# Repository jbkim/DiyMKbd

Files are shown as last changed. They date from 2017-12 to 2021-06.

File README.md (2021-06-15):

# Diy Mechanical Keyboard

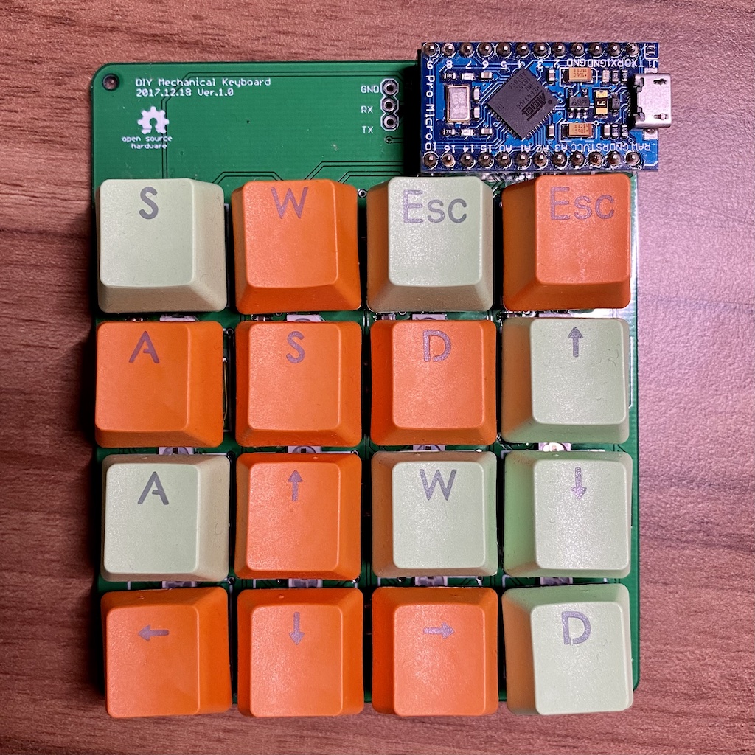
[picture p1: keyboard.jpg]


### Hardware
- WS2812B NeoPixel: 없어도 동작함 [Link](https://www.adafruit.com/product/1655)
- 기계식 키스위치: http://www.coupang.com/vp/products/24294727

### Firmware
- MyDiyKbd: 실제 동작하는 코드
- Tets_Neopixel, Tets_Neopixel2, Test_key : 테스트용 코드

### Order
- 중국 PCB 업체 https://jlcpcb.com/

### 참고
- http://blog.komar.be/how-to-make-a-keyboard-the-matrix/
- 아두이노 Keyboard Modifiers https://www.arduino.cc/en/Reference/KeyboardModifiers
- Mac 키보드 단축키 https://support.apple.com/ko-kr/HT201236

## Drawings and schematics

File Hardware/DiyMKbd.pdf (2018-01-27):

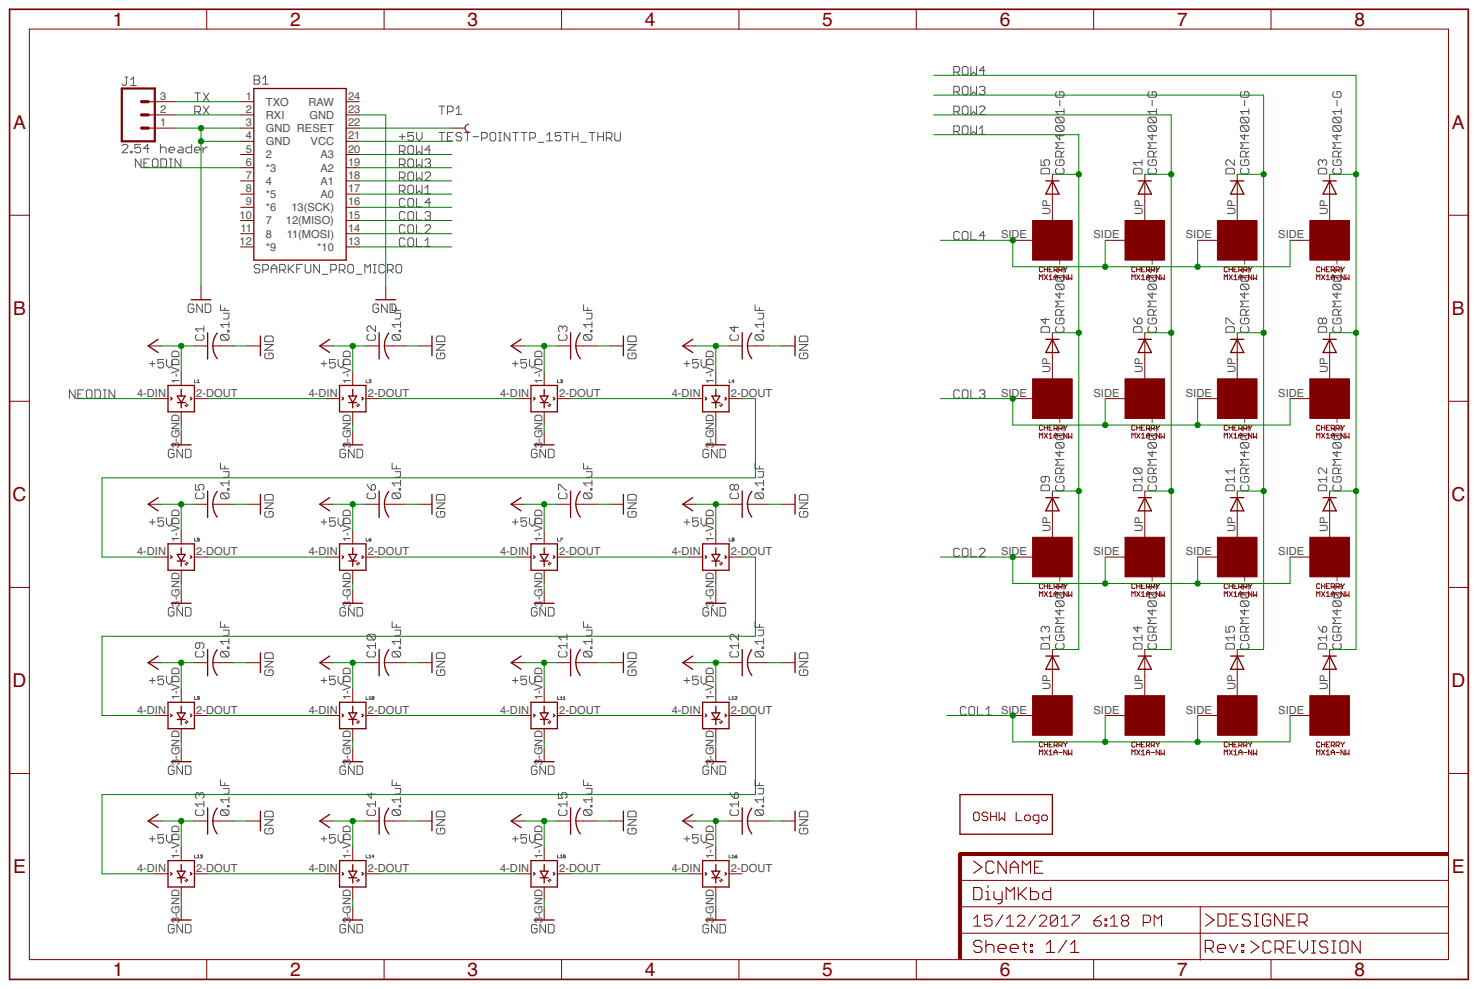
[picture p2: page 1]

UP UP A SIDE UP UP A SIDE UP UP A SIDE UP UP A SIDE UP UP A SIDE UP UP A SIDE UP UP A SIDE UP UP A SIDE UP UP A SIDE UP UP A SIDE UP UP A SIDE UP UP A SIDE UP UP A SIDE UP UP A SIDE UP UP A SIDE UP UP A SIDE 2 5 *3 6 4 7 *5 8 *6 9 7 10 8 11 *9 12 *10 13 11(MOSI) 14 12(MISO) 15 13(SCK) 16 A0 17 A1 18 A2 19 A3 20 GND 4 GND 23 RAW 24 GND 3 RESET 22 RXI 2 TXO 1 VCC 21 123 4-DIN 2-DOUT 1-VDD 3-GND 4-DIN 2-DOUT 1-VDD 3-GND 4-DIN 2-DOUT 1-VDD 3-GND 4-DIN 2-DOUT 1-VDD 3-GND 4-DIN 2-DOUT 1-VDD 3-GND 4-DIN 2-DOUT 1-VDD 3-GND 4-DIN 2-DOUT 1-VDD 3-GND 4-DIN 2-DOUT 1-VDD 3-GND 4-DIN 2-DOUT 1-VDD 3-GND 4-DIN 2-DOUT 1-VDD 3-GND 4-DIN 2-DOUT 1-VDD 3-GND 4-DIN 2-DOUT 1-VDD 3-GND 4-DIN 2-DOUT 1-VDD 3-GND 4-DIN 2-DOUT 1-VDD 3-GND 4-DIN 2-DOUT 1-VDD 3-GND 4-DIN 2-DOUT 1-VDD 3-GND ABCDE 1 2 3 4 5 6 7 8 ABCDE 1 2 3 4 5 6 7 8

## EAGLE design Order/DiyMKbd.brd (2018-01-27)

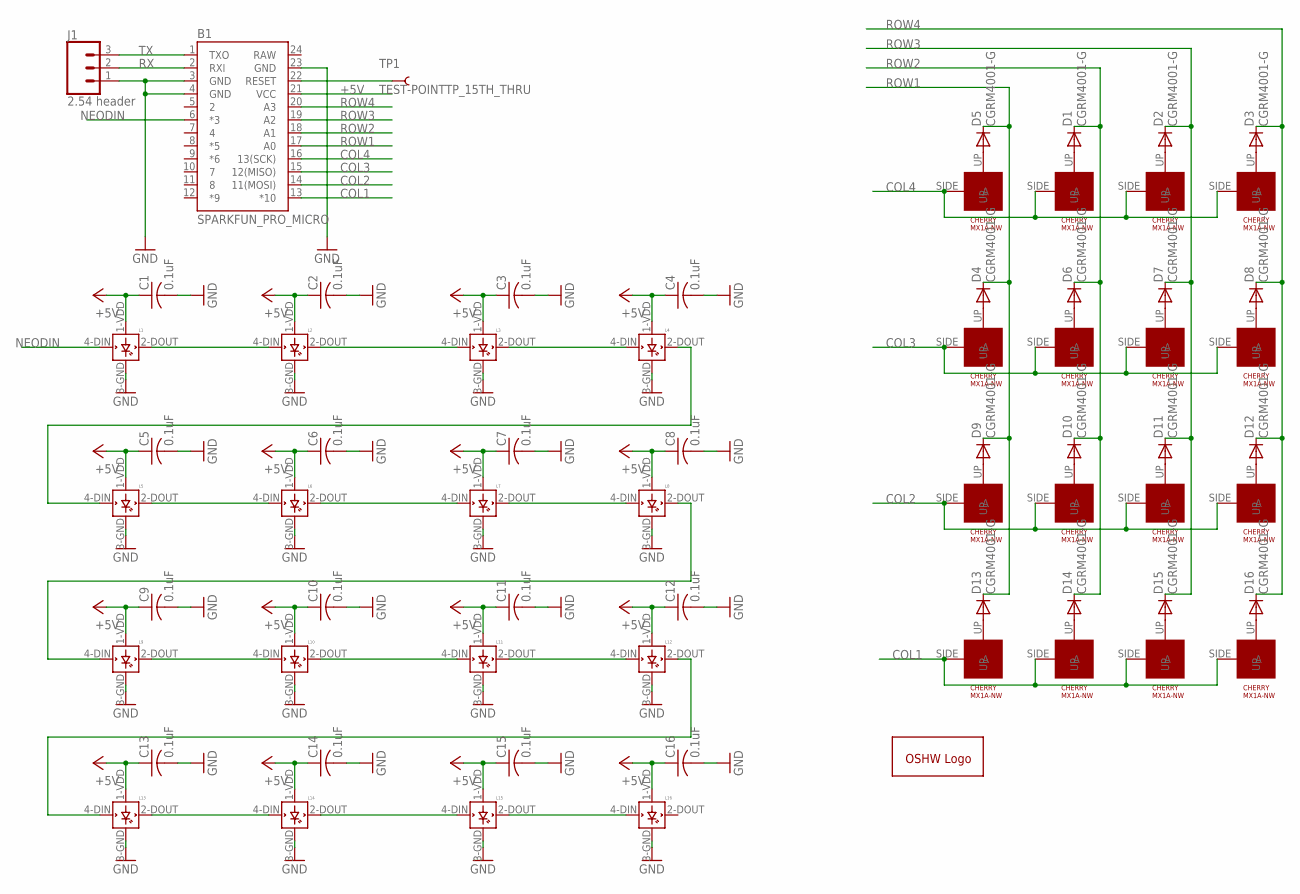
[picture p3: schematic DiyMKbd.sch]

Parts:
B1: SPARKFUN_PRO_MICRO
C1, C2, C3, C4, C5, C6, C7, C8, C9, C10, C11, C12, C13, C14, C15, C16: 0.1uF; C0603
D1, D2, D3, D4, D5, D6, D7, D8, D9, D10, D11, D12, D13, D14, D15, D16: CGRM4001-G; SOD-123_MINI-SMA
GOLD_ORB_SM1: OSHWLOGOLOGO5MM; OSHW_5MM
J1: 2.54 header; 1X03_LOCK
L1, L2, L3, L4, L5, L6, L7, L8, L9, L10, L11, L12, L13, L14, L15, L16: WS2812B
TP1: TEST-POINTTP_15TH_THRU; TP_15TH
U$1, U$2, U$3, U$4, U$7, U$8, U$9, U$10, U$19, U$20, U$21, U$22, U$25, U$26, U$27, U$28: CHERRY-MX1A-E1NW; CHERRYMX-NN

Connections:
+5V: B1.21 (VCC), C1.1, C2.1, C3.1, C4.1, C5.1, C6.1, C7.1, C8.1, C9.1, C10.1, C11.1, C12.1, C13.1, C14.1, C15.1, C16.1, L1.1-VDD (VDD), L2.1-VDD (VDD), L3.1-VDD (VDD), L4.1-VDD (VDD), L5.1-VDD (VDD), L6.1-VDD (VDD), L7.1-VDD (VDD), L8.1-VDD (VDD), L9.1-VDD (VDD), L10.1-VDD (VDD), L11.1-VDD (VDD), L12.1-VDD (VDD), L13.1-VDD (VDD), L14.1-VDD (VDD), L15.1-VDD (VDD), L16.1-VDD (VDD)
COL1: B1.13 (*10), U$25.SIDE (A), U$26.SIDE (A), U$27.SIDE (A), U$28.SIDE (A)
COL2: B1.14 (11(MOSI)), U$7.SIDE (A), U$8.SIDE (A), U$9.SIDE (A), U$10.SIDE (A)
COL3: B1.15 (12(MISO)), U$1.SIDE (A), U$2.SIDE (A), U$3.SIDE (A), U$4.SIDE (A)
COL4: B1.16 (13(SCK)), U$19.SIDE (A), U$20.SIDE (A), U$21.SIDE (A), U$22.SIDE (A)
GND: B1.3 (GND), B1.4 (GND), B1.23 (GND), C1.2, C2.2, C3.2, C4.2, C5.2, C6.2, C7.2, C8.2, C9.2, C10.2, C11.2, C12.2, C13.2, C14.2, C15.2, C16.2, J1.1, L1.3-GND (GND), L2.3-GND (GND), L3.3-GND (GND), L4.3-GND (GND), L5.3-GND (GND), L6.3-GND (GND), L7.3-GND (GND), L8.3-GND (GND), L9.3-GND (GND), L10.3-GND (GND), L11.3-GND (GND), L12.3-GND (GND), L13.3-GND (GND), L14.3-GND (GND), L15.3-GND (GND), L16.3-GND (GND)
unnamed: D5.A, U$19.UP
unnamed: D1.A, U$20.UP
unnamed: D2.A, U$21.UP
unnamed: D3.A, U$22.UP
unnamed: L1.2-DOUT (DOUT), L2.4-DIN (DIN)
unnamed: L2.2-DOUT (DOUT), L3.4-DIN (DIN)
unnamed: D4.A, U$2.UP
unnamed: D6.A, U$1.UP
unnamed: D7.A, U$3.UP
unnamed: D8.A, U$4.UP
unnamed: L3.2-DOUT (DOUT), L4.4-DIN (DIN)
unnamed: L4.2-DOUT (DOUT), L5.4-DIN (DIN)
unnamed: L5.2-DOUT (DOUT), L6.4-DIN (DIN)
unnamed: L6.2-DOUT (DOUT), L7.4-DIN (DIN)
unnamed: L7.2-DOUT (DOUT), L8.4-DIN (DIN)
unnamed: L8.2-DOUT (DOUT), L9.4-DIN (DIN)
unnamed: L9.2-DOUT (DOUT), L10.4-DIN (DIN)
unnamed: L10.2-DOUT (DOUT), L11.4-DIN (DIN)
unnamed: D9.A, U$7.UP
unnamed: D10.A, U$8.UP
unnamed: D11.A, U$9.UP
unnamed: D12.A, U$10.UP
unnamed: L11.2-DOUT (DOUT), L12.4-DIN (DIN)
unnamed: L12.2-DOUT (DOUT), L13.4-DIN (DIN)
unnamed: D13.A, U$25.UP
unnamed: D14.A, U$26.UP
unnamed: D15.A, U$27.UP
unnamed: D16.A, U$28.UP
unnamed: L13.2-DOUT (DOUT), L14.4-DIN (DIN)
unnamed: L14.2-DOUT (DOUT), L15.4-DIN (DIN)
unnamed: L15.2-DOUT (DOUT), L16.4-DIN (DIN)
NEODIN: B1.6 (*3), L1.4-DIN (DIN)
RAW: B1.24 (RAW)
RESET: B1.22 (RESET), TP1.P$1
ROW1: B1.17 (A0), D4.C, D5.C, D9.C, D13.C
ROW2: B1.18 (A1), D1.C, D6.C, D10.C, D14.C
ROW3: B1.19 (A2), D2.C, D7.C, D11.C, D15.C
ROW4: B1.20 (A3), D3.C, D8.C, D12.C, D16.C
RX: B1.2 (RXI), J1.2
TX: B1.1 (TXO), J1.3

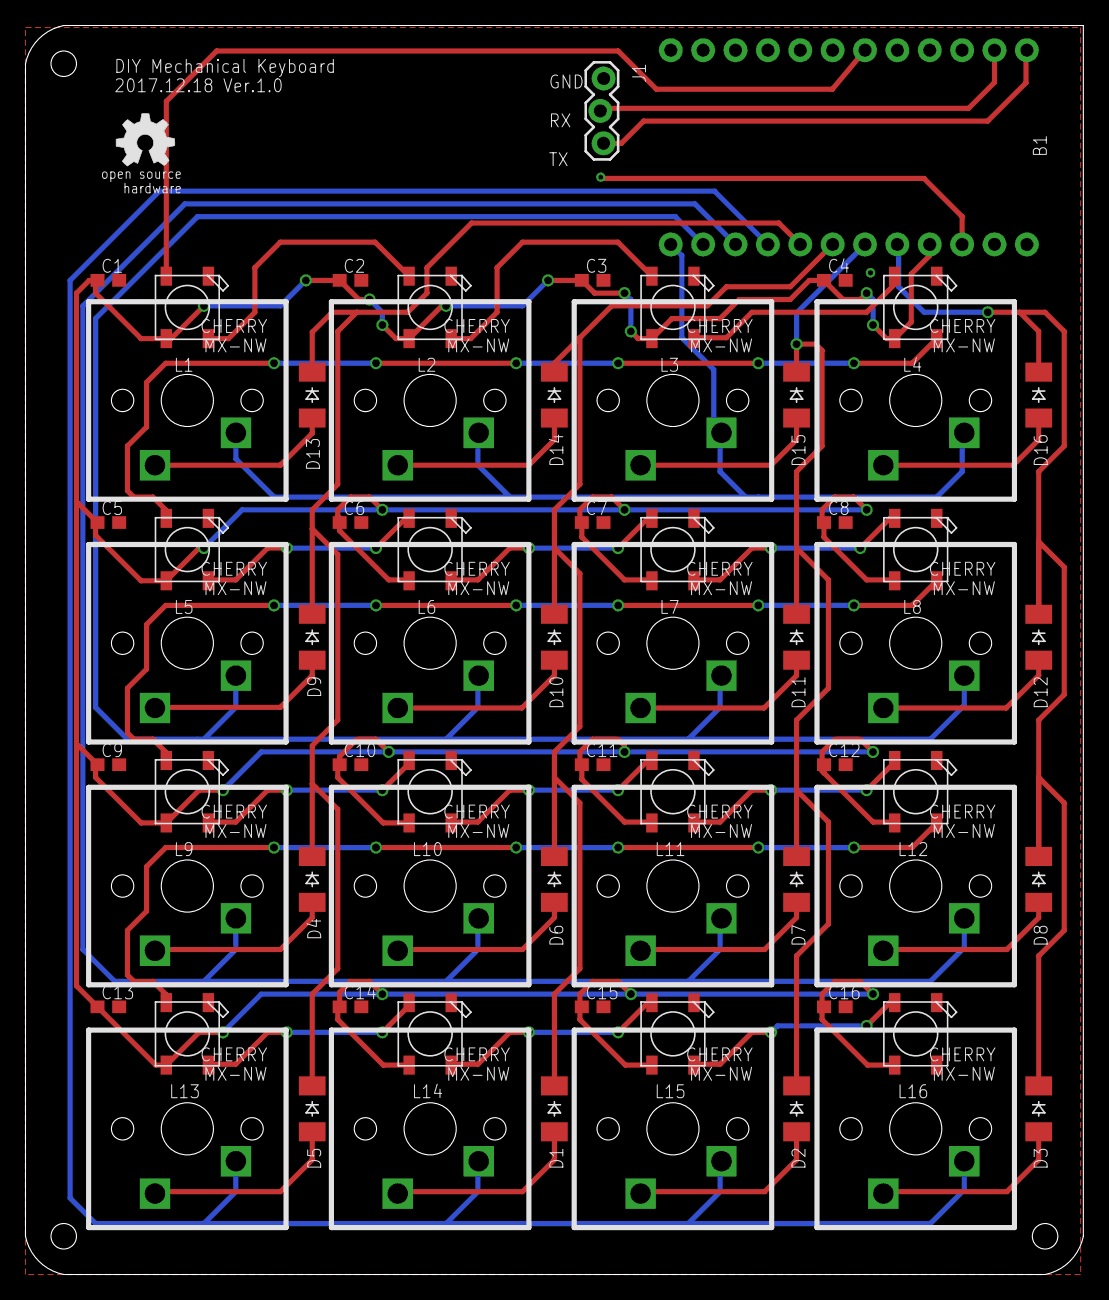
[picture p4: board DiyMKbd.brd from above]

Board: 2 copper layers, 83.0 x 98.0 mm, 68 parts (0 on the bottom side), 45 nets.

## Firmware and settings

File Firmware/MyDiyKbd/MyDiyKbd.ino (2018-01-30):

#include <HID-Project.h>
#include <Adafruit_NeoPixel.h>

#define NUM_BTN_COLS (4) // Number of switch columns (isolating diode anode)
#define NUM_BTN_ROWS (4) // Number of switch rows (isolating diode cathode)

// Debounce built-in to the code. This sets the number of button
// high or low senses that trigger a press or release
#define MAX_DEBOUNCE (3)
#define KEY_COMMAND KEY_LEFT_GUI

// Which pin on the Arduino is connected to the NeoPixels?
#define PIN            3

// How many NeoPixels are attached to the Arduino?
#define NUMPIXELS      16

static const uint8_t btnRowPins[NUM_BTN_ROWS] = {A0,A1,A2,A3}; // Pins connected to switch rows (2)
static const uint8_t btnColPins[NUM_BTN_COLS] = {10,16,14,15};; // Pins connected to switch columns (1)
static int8_t debounce_count[NUM_BTN_COLS][NUM_BTN_ROWS]; // One debounce counter per switch

Adafruit_NeoPixel pixels = Adafruit_NeoPixel(NUMPIXELS, PIN, NEO_GRB + NEO_KHZ800);

void showPixels(uint8_t row, uint8_t col, int r, int g, int b)
{
   pixels.setPixelColor(col*4 + row, pixels.Color(r,g,b));
   pixels.show();
   // delay(100);
}

void setup()
{
  uint8_t i, j;

  setupSwitchPins();

  // Initialize the debounce counter array
  for (i = 0; i < NUM_BTN_COLS; i++)
  {
    for (j = 0; j < NUM_BTN_ROWS; j++)
    {
      debounce_count[i][j] = 0;
    }
  }

// Initialize USB keyboard
  Keyboard.begin();
  
// Initialize Neopixel
  pixels.begin();
  colorWipe(pixels.Color(127, 127, 127), 50); // White

// Off
  for(i = 0; i < 4 ; i++){
    for(j = 0; j < 4 ; j++){
      showPixels(i,j,0,0,0);
      delay(50);
    }
  }
}

void loop() 
{
  scan();
}

static void scan()
{
  static uint8_t currentRow = 0;
  uint8_t i, j; // for loop counters
  int key;

  // Select current row, and write all components on that row LOW.
  // That'll set the LED anode's LOW, and write the switch "2" pins LOW.
  // If diodes were added, "2' should be connected to the diode cathode
  digitalWrite(btnRowPins[currentRow], LOW);
  // digitalWrite(ledRowPins[currentRow], LOW);

  // Scan through switches on this row:
  for ( j = 0; j < NUM_BTN_COLS; j++)
  {
    // Read the button. If it's pressed, it should be LOW.
    if (digitalRead(btnColPins[j]) == LOW)
    {
      if ( debounce_count[currentRow][j] < MAX_DEBOUNCE)
      { // Increment a debounce counter
        debounce_count[currentRow][j]++;
        if ( debounce_count[currentRow][j] == MAX_DEBOUNCE )
        { // If debounce counter hits MAX_DEBOUNCE (default: 3)
          // Trigger key press -- Do anything here...
          // Serial.print("Key pressed "); 
          // Serial.println((currentRow * NUM_BTN_COLS) + j);

          showPixels(currentRow, j, 0, 255, 0);  // green
          key = (currentRow * NUM_BTN_COLS) + j;
          // key = key + '0';
          // Keyboard.press(key); // Will display 0123456789:;<=>>?
          run_cmd(key);
        }
      }
    }
    else // Otherwise, button is released
    {
      if ( debounce_count[currentRow][j] > 0)
      { 
        debounce_count[currentRow][j]--; // Decrement debounce counter
        if ( debounce_count[currentRow][j] == 0 )
        { // If debounce counter hits 0
          // Trigger key release -- Do anything here...
          showPixels(currentRow, j, 0,0,0);  
          Keyboard.releaseAll();
        }
      }
    }
  }

  // Once done scanning, de-select the switch and LED rows
  // by writing them HIGH.
  digitalWrite(btnRowPins[currentRow], HIGH);

  // Increment currentRow, so next time we scan the next row
  currentRow++;
  // if (currentRow >= NUM_LED_ROWS)
  if (currentRow >= NUM_BTN_ROWS)
  {
    currentRow = 0;
  }
}

static void setupSwitchPins()
{
  uint8_t i;

  // Button drive rows - written LOW when active, HIGH otherwise
  for (i = 0; i < NUM_BTN_ROWS; i++)
  {
    pinMode(btnRowPins[i], OUTPUT);

    // with nothing selected by default
    digitalWrite(btnRowPins[i], HIGH);
  }

  // Buttn select columns. Pulled high through resistor. Will be LOW when active
  for (i = 0; i < NUM_BTN_COLS; i++)
  {
    pinMode(btnColPins[i], INPUT_PULLUP);
  }
}


// Fill the dots one after the other with a color
void colorWipe(uint32_t c, uint8_t wait) {
  for(uint16_t i = 0; i < pixels.numPixels(); i++) {
    pixels.setPixelColor(i, c);
    pixels.show();
    delay(wait);
  }
}

// Input a value 0 to 255 to get a color value.
// The colours are a transition r - g - b - back to r.
uint32_t Wheel(byte WheelPos) 
{
  WheelPos = 255 - WheelPos;
  if(WheelPos < 85) {
    return pixels.Color(255 - WheelPos * 3, 0, WheelPos * 3);
  }
  if(WheelPos < 170) {
    WheelPos -= 85;
    return pixels.Color(0, WheelPos * 3, 255 - WheelPos * 3);
  }
  WheelPos -= 170;
  return pixels.Color(WheelPos * 3, 255 - WheelPos * 3, 0);
}


void rainbow(uint8_t wait) {
  uint16_t i, j;

  for(j = 0; j < 256; j++) {
    for(i = 0; i < pixels.numPixels(); i++) {
      pixels.setPixelColor(i, Wheel((i+j) & 255));
    }
    pixels.show();
    delay(wait);
  }
}


void run_cmd(uint8_t key)
{
  switch(key) {
    // 1
    case 0:
      Keyboard.press(KEY_LEFT_GUI);
      Keyboard.press(KEY_LEFT_CTRL);
      Keyboard.press('q');    
      break;    
    case 1:
      // select all
      Keyboard.press(KEY_LEFT_GUI);
      Keyboard.press('a');    
      break;
    case 2:
      // alt + space = Spotlight
      Keyboard.press(KEY_LEFT_ALT);
      Keyboard.press(' ');  
      break;
    case 3:
      Keyboard.press(KEY_LEFT_ARROW);
      break;
    // 2
    case 4:
      // close window
      Keyboard.press(KEY_LEFT_GUI);
      Keyboard.press('w');    
      break;
    case 5:
      break;
    case 6:
      Keyboard.press(KEY_UP_ARROW);
      break;
    case 7:
      Keyboard.press(KEY_DOWN_ARROW);
      break;
    // 3
    case 8:
      break;
    case 9:
      break;
    case 10:
      break;
    case 11:
      Keyboard.press(KEY_RIGHT_ARROW);    
      break;

    // 4
    case 12:
      // log out
      Keyboard.press(KEY_LEFT_GUI);
      // Shift-Q logs out:
      Keyboard.press(KEY_LEFT_SHIFT);
      Keyboard.press('q');      
      delay(100);
      Keyboard.releaseAll();
      // enter:
      // Keyboard.write(KEY_RETURN);      
      break;
    case 13:
      Keyboard.press(KEY_PAGE_UP);
      break;
    case 14:
      Keyboard.press(KEY_PAGE_DOWN);
      break;
    case 15:
      // enter
      Keyboard.write(KEY_RETURN);   
      break;
  }
}

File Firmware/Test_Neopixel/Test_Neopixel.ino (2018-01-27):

#include <NeoPixelAnimator.h>
#include <NeoPixelBrightnessBus.h>
#include <NeoPixelBus.h>

// NeoPixel Ring simple sketch (c) 2013 Shae Erisson
// released under the GPLv3 license to match the rest of the AdaFruit NeoPixel library

#include <Adafruit_NeoPixel.h>
#ifdef __AVR__
  #include <avr/power.h>
#endif

// Which pin on the Arduino is connected to the NeoPixels?
// On a Trinket or Gemma we suggest changing this to 1
#define PIN            3
#define GAP           20
// How many NeoPixels are attached to the Arduino?
#define NUMPIXELS      16

// When we setup the NeoPixel library, we tell it how many pixels, and which pin to use to send signals.
// Note that for older NeoPixel strips you might need to change the third parameter--see the strandtest
// example for more information on possible values.
Adafruit_NeoPixel pixels = Adafruit_NeoPixel(NUMPIXELS, PIN, NEO_GRB + NEO_KHZ800);
#define HSB
int delayval = 10; // delay for half a second
uint8_t c[3];

void hsb2rgb(uint16_t index, uint8_t sat, uint8_t bright, uint8_t color[3])
{
  uint16_t r_temp, g_temp, b_temp;
  uint8_t index_mod;
  uint8_t inverse_sat = (sat ^ 255);

  index = index % 768;
  index_mod = index % 256;

  if (index < 256)
  {
    r_temp = index_mod ^ 255;
    g_temp = index_mod;
    b_temp = 0;
  }

  else if (index < 512)
  {
    r_temp = 0;
    g_temp = index_mod ^ 255;
    b_temp = index_mod;
  }

  else if ( index < 768)
  {
    r_temp = index_mod;
    g_temp = 0;
    b_temp = index_mod ^ 255;
  }

  else
  {
    r_temp = 0;
    g_temp = 0;
    b_temp = 0;
  }

  r_temp = ((r_temp * sat) / 255) + inverse_sat;
  g_temp = ((g_temp * sat) / 255) + inverse_sat;
  b_temp = ((b_temp * sat) / 255) + inverse_sat;

  r_temp = (r_temp * bright) / 255;
  g_temp = (g_temp * bright) / 255;
  b_temp = (b_temp * bright) / 255;

  color[0]  = (uint8_t)r_temp;
  color[1]  = (uint8_t)g_temp;
  color[2] = (uint8_t)b_temp;
}



void setup() {
  // This is for Trinket 5V 16MHz, you can remove these three lines if you are not using a Trinket
#if defined (__AVR_ATtiny85__)
  if (F_CPU == 16000000) clock_prescale_set(clock_div_1);
#endif
  // End of trinket special code
  Serial.begin(115200);
  pixels.begin(); // This initializes the NeoPixel library.
  pinMode(10,INPUT);
}

void loop() {
#if 0
  // For a set of NeoPixels the first NeoPixel is 0, second is 1, all the way up to the count of pixels minus one.
  int dr = digitalRead(10);
  Serial.print("Read Data:");
  Serial.println(dr);
  if(dr){
   pixels.setPixelColor(0,pixels.Color(0,255,0));
   pixels.show();
   delay(100);
    
  }else{
   pixels.setPixelColor(0,pixels.Color(255,0,0));
   pixels.show();
   delay(100);
    
  }
#endif

    for(int j = 0; j < 767 ; j+=5){
       
       for(int i=0;i<NUMPIXELS;i++){
        hsb2rgb(j+GAP*0,255,255,c);
         pixels.setPixelColor(0,pixels.Color(c[0],c[1],c[2])); // Moderately bright green color.
         hsb2rgb((j+GAP*1)%767,255,255,c);
        pixels.setPixelColor(1,pixels.Color(c[0],c[1],c[2])); // Moderately bright green color.
        pixels.setPixelColor(4,pixels.Color(c[0],c[1],c[2])); // Moderately bright green color.
         hsb2rgb((j+GAP*2)%767,255,255,c);
         pixels.setPixelColor(2,pixels.Color(c[0],c[1],c[2])); // Moderately bright green color.
        pixels.setPixelColor(5,pixels.Color(c[0],c[1],c[2])); // Moderately bright green color.
        pixels.setPixelColor(8,pixels.Color(c[0],c[1],c[2])); // Moderately bright green color.
        hsb2rgb((j+GAP*3)%767,255,255,c);
         pixels.setPixelColor(3,pixels.Color(c[0],c[1],c[2])); // Moderately bright green color.
        pixels.setPixelColor(6,pixels.Color(c[0],c[1],c[2])); // Moderately bright green color.
        pixels.setPixelColor(9,pixels.Color(c[0],c[1],c[2])); // Moderately bright green color.
        pixels.setPixelColor(12,pixels.Color(c[0],c[1],c[2])); // Moderately bright green color.
        hsb2rgb((j+GAP*4)%767,255,255,c);
         pixels.setPixelColor(7,pixels.Color(c[0],c[1],c[2])); // Moderately bright green color.
        pixels.setPixelColor(10,pixels.Color(c[0],c[1],c[2])); // Moderately bright green color.
        pixels.setPixelColor(13,pixels.Color(c[0],c[1],c[2])); // Moderately bright green color.
        hsb2rgb((j+GAP*5)%767,255,255,c);
         pixels.setPixelColor(11,pixels.Color(c[0],c[1],c[2])); // Moderately bright green color.
        pixels.setPixelColor(14,pixels.Color(c[0],c[1],c[2])); // Moderately bright green color.
        hsb2rgb((j+GAP*6)%767,255,255,c);
         pixels.setPixelColor(15,pixels.Color(c[0],c[1],c[2])); // Moderately bright green color.
        
       }
       pixels.show(); // This sends the updated pixel color to the hardware.
      
       delay(delayval); // Delay for a period of time (in milliseconds).
    }
    


}

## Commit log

2017-12-15 add gerber file
    [DiyMKbd.brd, DiyMKbd.sch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]
2017-12-18 Add hole & rounding edge
    [DiyMKbd.brd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]
2018-01-27 update board file
    [DiyMKbd.brd]

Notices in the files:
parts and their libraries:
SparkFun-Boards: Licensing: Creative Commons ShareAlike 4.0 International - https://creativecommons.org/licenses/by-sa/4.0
